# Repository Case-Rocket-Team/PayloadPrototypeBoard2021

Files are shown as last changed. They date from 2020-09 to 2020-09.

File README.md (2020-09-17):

This is a prototype board for the 2021 ESRA Payload. We are planning on developing a parafoil guided payload that will be ejected from the rocket at apogee, and guide itself to landing. 

Capabilities of this board include: 
  6 Servo Outputs
  4 External IO 
  High Acceleration Accelerometer (H3LIS331DLTR)
  9 Axis IMU (ICM-20948) 
  LORA Radio (RFM98) 
  Barometer (BMP388) 
  18V Max Input
  Battery Voltage Reader
  Various LEDs for status 

This board should be used on the scale test payload we are developing, and will be a proof of concept for the final ESRA payload we will develop after validating this design.

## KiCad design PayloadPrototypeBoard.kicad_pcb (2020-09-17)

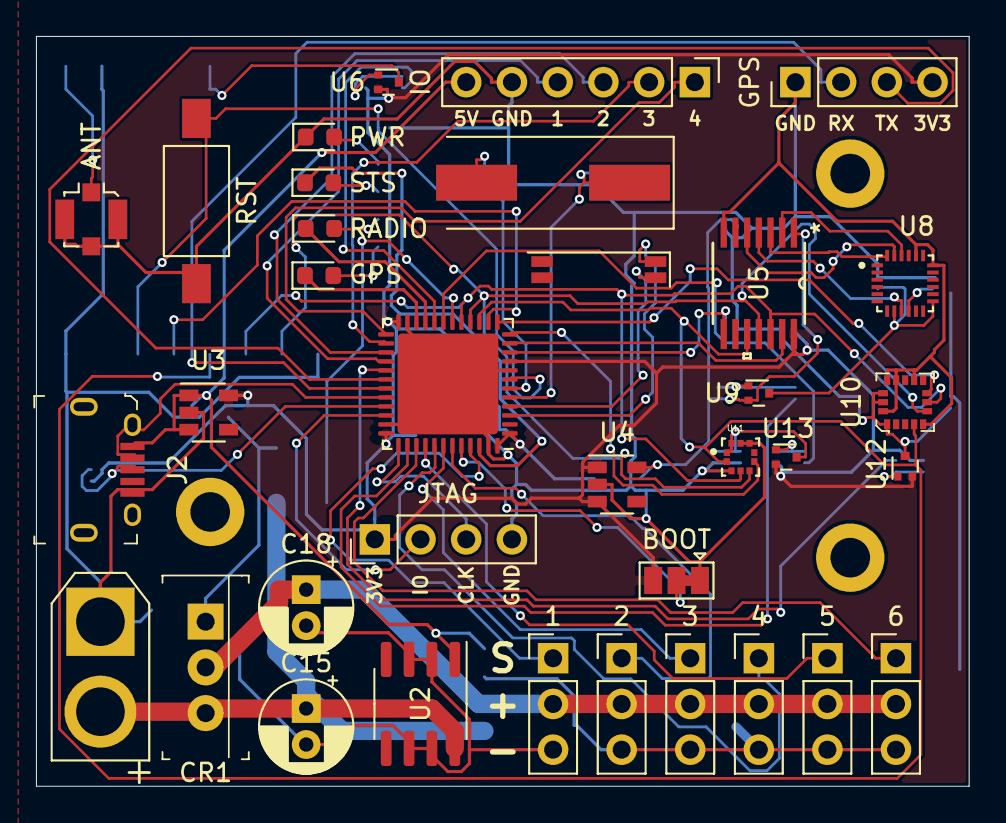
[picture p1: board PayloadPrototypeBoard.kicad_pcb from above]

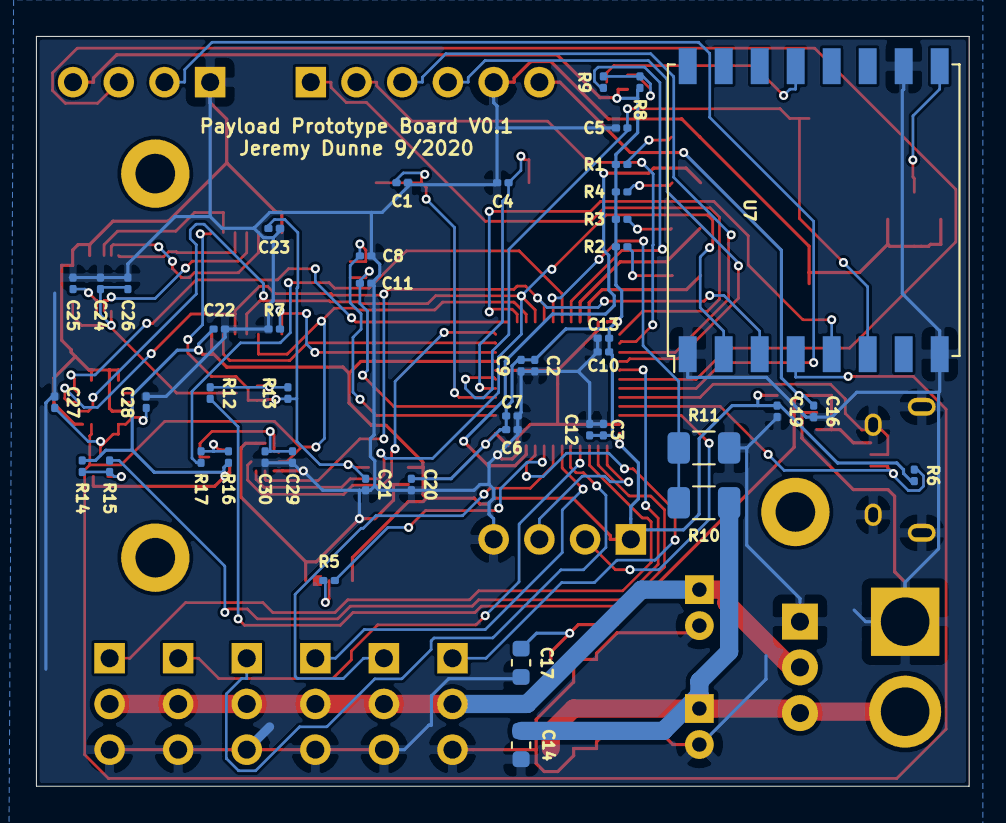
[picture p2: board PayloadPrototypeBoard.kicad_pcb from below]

Board: 2 copper layers, 51.8 x 41.7 mm, 84 parts (46 on the bottom side), 63 nets.

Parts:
1: SERVO 1; PinHeader_1x03_P2.54mm_Vertical
2: SERVO 2; PinHeader_1x03_P2.54mm_Vertical
3: SERVO 3; PinHeader_1x03_P2.54mm_Vertical
4: SERVO 4; PinHeader_1x03_P2.54mm_Vertical
5: SERVO 5; PinHeader_1x03_P2.54mm_Vertical
6: SERVO 6; PinHeader_1x03_P2.54mm_Vertical
ANT: Conn_Coaxial; U.FL_Molex_MCRF_73412-0110_Vertical
BOOT: BOOT0; SolderJumper-3_P1.3mm_Bridged12_Pad1.0x1.5mm
C1, C4: 20pF; C_0201_0603Metric
C2, C16, C19, C20, C21: 1uF; C_0201_0603Metric
C3: 10nF; C_0201_0603Metric
C5, C6, C9, C10, C12, C22, C23, C24, C25, C26, C29, C30: 0.1uF; C_0201_0603Metric
C7, C13: 4.7uF; C_0201_0603Metric
C8, C11: 10pF; C_0201_0603Metric
C14: 0.33uF; C_0603_1608Metric
C15, C18: 10uF; CP_Radial_D5.0mm_P2.00mm
C17: 0.1uF; C_0603_1608Metric
C27: 10uF; C_0201_0603Metric
C28: .1uF; C_0201_0603Metric
CR1: LD1085V50; TO-220-3
GPS: GPS_LOCK; LED_0603_1608Metric
GPS#2: GPS; PinHeader_1x04_P2.54mm_Vertical
H1, H2, H3: MountingHole; MountingHole_2.2mm_M2_DIN965_Pad
IO: EXTERNAL IO; PinHeader_1x06_P2.54mm_Vertical
J2: USB_OTG; USB_Micro_B_Female_10118194-0001LF
J9: PWR; AMASS_XT30U-F_1x02_P5.0mm_Vertical
JTAG: JTAG; PinHeader_1x04_P2.54mm_Vertical
PWR: PWR; LED_0603_1608Metric
R1, R2, R3, R4, R5, R7, R8, R9, R12, R13, R14, R15, R16, R17: 10K; R_0201_0603Metric
R6: 1.5K; R_0201_0603Metric
R10: 10K; R_1206_3216Metric
R11: 2.5k; R_1206_3216Metric
RADIO: RADIO_LOCK; LED_0603_1608Metric
RST: RESET; SW_SPST_FSMSM
STS: STATUS; LED_0603_1608Metric
U1: STM32F072C8Ux; QFN-48-1EP_7x7mm_P0.5mm_EP5.6x5.6mm
U2: L78L05_SO8; SOIC-8_3.9x4.9mm_P1.27mm
U3: MIC5504-3.3YM5; SOT-23-5
U4: MIC5504-1.8YM5; SOT-23-5
U5: TXS0104EPWR
U6, U9, U12, U13: SSM3J15FV; SOT-723
U7: RFM96W-433S2; HOPERF_RFM9XW_SMD
U8: ICM-20948; QFN40P300X300X105-24N
U10: H3LIS331DLTR; TFLGA-16_3x3mm
U11: BMP388; PQFN50P200X200X80-10N
Y1: 8MHz; Crystal_SMD_HC49-SD
Y2: 32Khz; Crystal_SMD_SeikoEpson_MC146-4Pin_6.7x1.5mm

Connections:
+1V8: C21.1, C23.2, R13.1, U4.5, U5.1, U9.2
+3V3: BOOT.3, C2.1, C3.1, C6.1, C7.1, C9.1, C10.1, C12.1, C13.1, C19.1, C20.1, C22.1, GPS#2.4, JTAG.1, R1.2, R2.2, R3.2, R4.2, R6.2, R8.2, R14.1, R16.2, U1.1, U1.9, U1.24, U1.36, U1.48, U3.5, U4.1, U4.3, U5.14, U6.2, U12.2, U13.2
+5V: C16.1, C17.1, IO.6, J2.1, U2.1, U3.1, U3.3
ACCEL_CS: U1.13, U10.8
ACCEL_EN: R15.1, U1.29
BARO_EN: R17.1, U1.19
BMP_CS: U1.12, U11.6
BOOT0: R5.2, U1.44
GND: 1.3, 2.3, 3.3, 4.3, 5.3, 6.3, ANT.2, BOOT.1, C1.2, C2.2, C3.2, C4.2, C5.2, C6.2, C7.2, C8.2, C9.2, C10.2, C11.2, C12.2, C13.2, C14.2, C15.2, C16.2, C17.2, C18.2, C19.2, C20.2, C21.2, C22.2, C23.1, C24.1, C25.1, C26.1, C27.2, C28.2, C29.1, C30.2, CR1.1, GPS#2.1, IO.5, J2.5, J2.SH, J9.1, JTAG.4, PWR.1, R7.1, R11.2, RST.1, U1.8, U1.23, U1.35, U1.47, U1.49, U2.2, U2.3, U2.6, U2.7, U3.2, U4.2, U5.7, U7.1, U7.8, U7.10, U8.18, U8.20, U10.5, U10.10, U10.12, U10.13, U10.16, U11.3, U11.8, U11.9
GPS_LOCK_LED: GPS.1, U1.22
GPS_RX: GPS#2.2, U1.31
GPS_TX: GPS#2.3, U1.30
IMU_CS: U1.11, U5.13
IMU_EN: R12.2, U1.38
IO_1: IO.4, U1.28
IO_2: IO.3, U1.27
IO_3: IO.2, U1.26
IO_4: IO.1, U1.25
MISO_3V3: U1.16, U5.11, U7.2, U10.6, U11.5
MOSI_3V3: U1.17, U5.12, U7.3, U10.7, U11.4
unnamed: C24.2, C26.2, U8.8, U8.13, U9.3
unnamed: C25.2, U8.10
unnamed: C27.1, C28.1, U10.1, U10.14, U10.15, U12.3
unnamed: C29.2, C30.1, U11.1, U11.10, U13.3
unnamed: PWR.2, R1.1
unnamed: GPS.2, R2.1
unnamed: R3.1, RADIO.2
unnamed: R4.1, STS.2
unnamed: ANT.1, U7.9
unnamed: BOOT.2, R5.1
unnamed: R8.1, R9.2, U6.1
unnamed: R12.1, R13.2, U9.1
unnamed: R14.2, R15.2, U12.1
unnamed: R16.1, R17.2, U13.1
unnamed: U5.2, U8.22
unnamed: U5.3, U8.24
unnamed: U5.4, U8.9
unnamed: U5.5, U8.23
unnamed: U6.3, U7.13
OE: R7.2, U1.10, U5.8
OSC32_IN: C8.1, U1.3, Y2.1
OSC32_OUT: C11.1, U1.4, Y2.4
OSC_IN: C1.1, U1.5, Y1.1
OSC_OUT: C4.1, U1.6, Y1.2
RADIO_CS: U1.14, U7.5
RADIO_EN: R9.1, U1.20
RADIO_LOCK_LED: RADIO.1, U1.21
RST: C5.1, RST.2, U1.7, U7.6
SCK_3V3: U1.15, U5.10, U7.4, U10.4, U11.2
SERVO_1: 1.1, U1.45
SERVO_2: 2.1, U1.43
SERVO_3: 3.1, U1.42
SERVO_4: 4.1, U1.41
SERVO_5: 5.1, U1.40
SERVO_6: 6.1, U1.39
SERVO_PWR: 1.2, 2.2, 3.2, 4.2, 5.2, 6.2, C18.1, CR1.2
STATUS_LED: STS.1, U1.46
SWCLK: JTAG.3, U1.37
SWDIO: JTAG.2, U1.34
USB_DM: J2.2, U1.32
USB_DP: J2.3, R6.1, U1.33
VIN: C14.1, C15.1, CR1.3, J9.2, R10.1, U2.8
VOLTAGE_READ: R10.2, R11.1, U1.18

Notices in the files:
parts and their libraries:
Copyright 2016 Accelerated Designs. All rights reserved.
